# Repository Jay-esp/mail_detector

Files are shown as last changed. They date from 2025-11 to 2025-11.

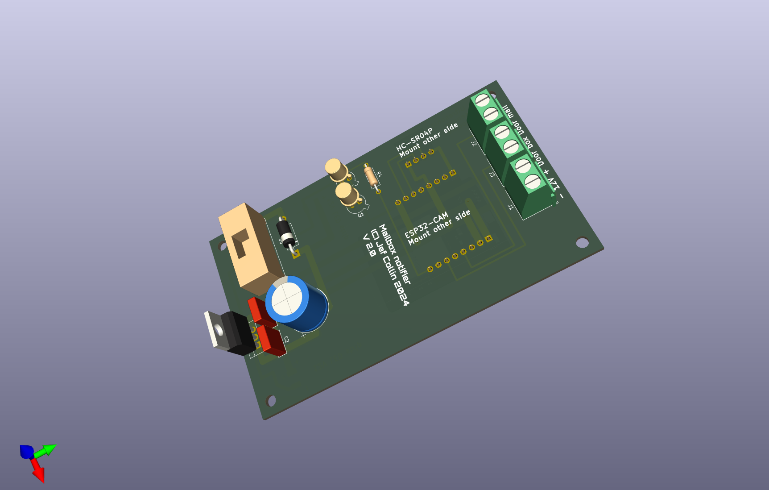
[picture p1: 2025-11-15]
design_pcb_schematic/mailbox_esp32_cam_v2_0_top.png

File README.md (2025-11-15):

Purpose is to send a mail and a picture when something is put in my physical mailbox.
This project is a new version of a mail detector i designed some time ago and that one served well for over 7 years.
The original version had an ESP8266, no camera, in 7 years i had to replace a reed contact due to poor quality and oxidation and update the software twice because the mail authenticiation for gmail changed.

My problem, i have a large brick mailbox in front of my house with a mail slot and in the back a separate door and storage for larger deliveries, i'm surprised how many notice the compartment and use it.

Mail, advertising, online order delivery... these days it can be at any time, sometimes they don't push it all the way in and when it rains i get soggy mail.

So i wanted a warning system that sends me a mail when something is put in either the mailbox or "box" box.

One of the challenges is that the mail slot is open, there is no flap or anything that moves when mail is put in.

The original concept was based on ESP8266 and a ultrasonic sensor HC-SR04P (3.3v version!), it is mounted above the slot and measures the distance to the floor of the mailbox, if the distance is short it means something is passing in the slot and it then activates wifi and sends a mail. Both doors have a reed sensor so i also get a notice when the box compartment is opened. I included a few leds to light the mailbox inside when i open the door, very handy at night, when i open the door that ignores any triggers that might happen when i pull stuck mail out of the flap. Of course a lot of extras such as stuck mail detection or door that is still open etc...

One of the challenges was power, i did have a socarex pipe nearby that only had the TV cable so i made an opening and ran a cable though it to my garage where a power supply is hooked up, to allow for a long cable i placed the 5v regulator in the mailbox so losses are no issue.

The version published here is a new design based on a ESP32-CAM and can take a picture of the mail, the same ultrasonic sensor is used, i changed the reed switches to a sealed version.

As usuall i use Arduino 1 IDE in portable mode to avoid the many issues with breaking changes in libraries.
I use the dedicated programming board they sell for the ESP32-CAM module since it has no USB-serial bridge on it.

Standard disclaimer: it works for me, i have no responsibility over what you make, use as inspiration or idea for your own project.

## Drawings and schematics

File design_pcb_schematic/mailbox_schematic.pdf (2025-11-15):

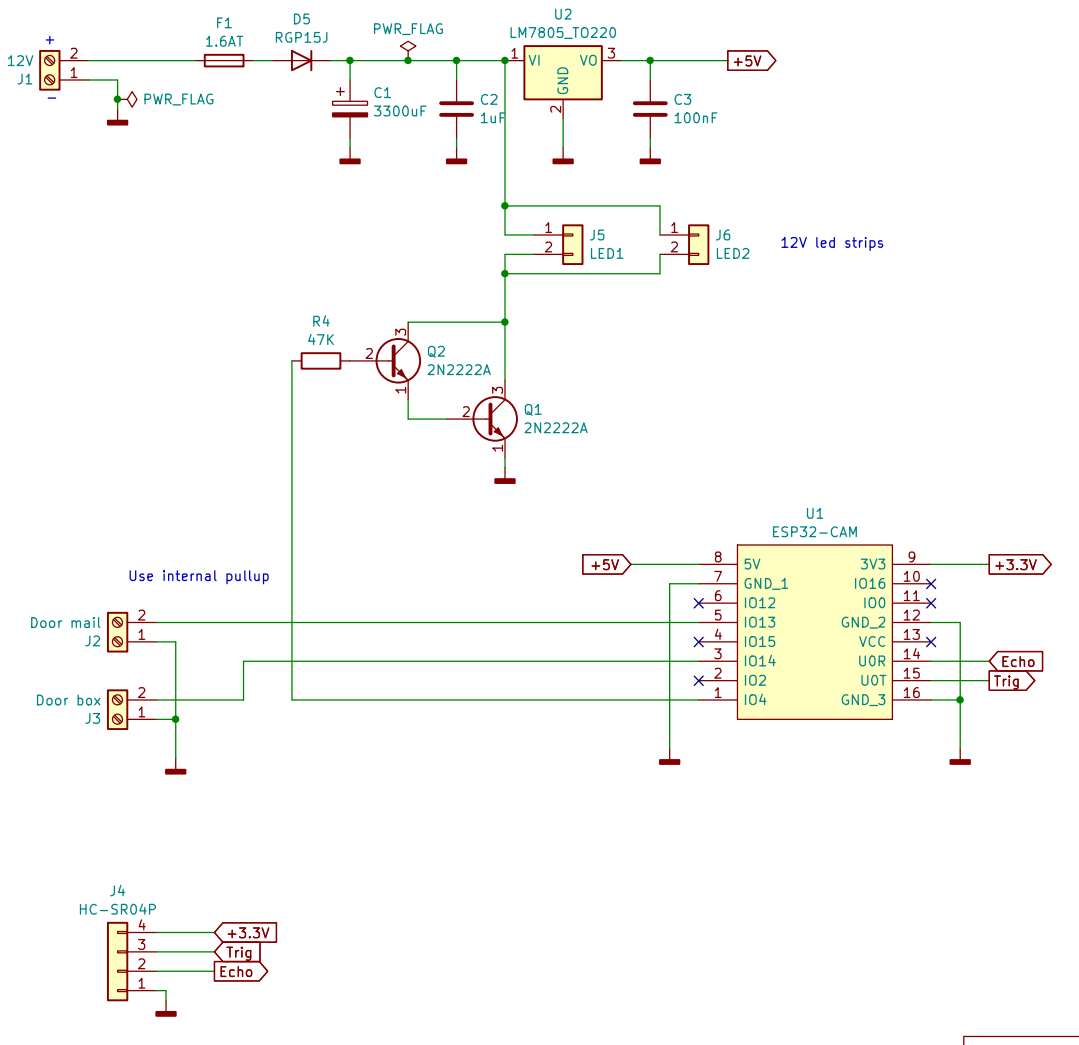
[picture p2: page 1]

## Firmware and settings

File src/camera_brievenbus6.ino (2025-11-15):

// mailbox detector
// Jef Collin 2024
// V 1.0


// todo


#include "esp_camera.h"
#include <WiFi.h>
#include "driver/rtc_io.h"
#include <ESP_Mail_Client.h>

boolean debugloop = false;

// wifi parameters
const char* ssid = "your_ssid";
const char* password = "your_password";

// SMTP parameters
#define AUTHOR_EMAIL    "xxx@gmail.com"
#define AUTHOR_PASSWORD "replace! make in gmail authenticiation"
#define SMTP_HOST        "smtp.gmail.com"
#define SMTP_PORT        465
#define RECIPIENT_EMAIL  "xxx@gmail.com"

#define EmailSubject     "My letterbox"

// cap on messages per day
#define MaximumMessagesPerDay 10

#define CAMERA_MODEL_AI_THINKER // Has PSRAM
#include <camera_pins.h>

// echo from sensor
#define Pin_Echo 3
// trigger for sensor
#define Pin_Trigger 1
// doorcontact mailbox
#define Pin_Door_Letter 13
// doorcontact packages
#define Pin_Door_Box 14
// LED strip
#define Pin_LEDS 4

// global buffer to duplicate picture buffer into so original buffer can be freed
uint8_t *PictureBuffer = NULL;
size_t PictureBufferLen = 0;

// distance measured
long EchoDistance = 0;

// trigger threshold in cm, modify as needed
int EchoTriggerDistance = 25;

// sensor triggered
boolean EchoTriggered = false;

// ignore echo sensor trigger if mailbox door is open
boolean EchoIgnoreTrigger = false;

// change status for echo and switches
boolean EchoStatus = false;
boolean PreviousEchoStatus = false;

byte LetterDoorStatus = 0;
byte PreviousLetterDoorStatus = 2;

byte BoxDoorStatus = 0;
byte PreviousBoxDoorStatus = 2;

// letter door open
boolean LetterDoorTriggered = false;

// if warning for open letter door is sent
boolean LetterDoorStillOpenWarningSent = false;

// box door open
boolean BoxDoorTriggered = false;

// if warning for open box door is sent
boolean BoxDoorStillOpenWarningSent = false;

// ignore box door if opened by me, open letter door first
boolean IgnoreBoxDoorTrigger = false;

// mail is stuck in opening
boolean MailStuck = false;

// LEDs status
boolean LEDIsOn = false;

// count number of emails, limit mails per day
int EmailCounter = 0;

// timer for sensors
unsigned long TimerEcho  = millis();
unsigned long TimerLetterDoor  = millis();
unsigned long TimerBoxDoor  = millis();

// timer for LEDs
unsigned long TimerLED  = millis();

// timer for mails per day
unsigned long TimerEmailLimit  = millis();

// minus 10 minutes to ensure mail is detected within time limit
unsigned long LastTrigger  = millis() - 600000;

// global used SMTPSession object for SMTP transport
SMTPSession smtp;

// global used Session_Config for user defined session credentials
Session_Config config;

/* callback function to get the Email sending status */
void smtpCallback(SMTP_Status status);

void setup() {
  if (debugloop) {
    Serial.begin(115200);
  }

  // configure inputs and outputs
  if (!debugloop) {
    pinMode(Pin_Trigger, OUTPUT);
    pinMode(Pin_Echo, INPUT);
    pinMode(Pin_Door_Letter, INPUT_PULLUP);
    pinMode(Pin_Door_Box, INPUT_PULLUP);
  }

  pinMode(Pin_LEDS, OUTPUT);
  digitalWrite(Pin_LEDS, LOW);

  // allow pins to settle
  delay(200);

  // make sure wifi is disabled
  WiFi.disconnect(true);

  WiFi.mode(WIFI_OFF);

  if (!debugloop) {
    // first measurement for power on mail
    EchoDistance = MeasureDistance();
  }

  //  network reconnection option
  MailClient.networkReconnect(true);

  // callback function to get the sending results
  smtp.callback(smtpCallback);

  if (debugloop) {
    //   smtp.debug(1);
  }

  // send startup mail
  SendMail(4, true);

  delay(5000);

}

void loop() {

  if (!debugloop) {

    // get door switches
    LetterDoorStatus = digitalRead(Pin_Door_Letter);
    BoxDoorStatus = digitalRead(Pin_Door_Box);

    // letter door flow
    if (LetterDoorStatus != PreviousLetterDoorStatus) {
      // letter door open
      if (LetterDoorStatus == 1) {
        // door opened
        // to avoid mails if we open the box door ignore triggers when letter door is open
        IgnoreBoxDoorTrigger = true;
        // ignore echo triggers if letter door open in case we need to pull out mail from the slot or push stuck mail in
        EchoIgnoreTrigger = true;
        // clear triggered
        EchoTriggered = false;
        // set trigger flag
        LetterDoorTriggered = true;
        // allow new mails
        EmailCounter = 0;
        // reset timer
        TimerEmailLimit = millis();
        // start timer
        TimerLetterDoor  = millis();
        // turn led on
        digitalWrite(Pin_LEDS, HIGH);
        LEDIsOn = true;
        // start timer
        TimerLED  = millis();
      }
      else
      {
        // reset, allow mails for box door
        IgnoreBoxDoorTrigger = false;
        // reset, arm echo sensor
        EchoIgnoreTrigger = false;
        // turn led off if still on
        if (LEDIsOn) {
          digitalWrite(Pin_LEDS, LOW);
          LEDIsOn = false;
        }
        LetterDoorTriggered = false;
        LetterDoorStillOpenWarningSent = false;
      }
      PreviousLetterDoorStatus = LetterDoorStatus;
    }

    // send warning once if still open after a while
    if (LetterDoorTriggered and millis() - TimerLetterDoor >= 300000 and !LetterDoorStillOpenWarningSent) {
      // door still open
      SendMail(3, false);
      // set flag to prevent from sending warning again
      LetterDoorStillOpenWarningSent = true;
    }

    // catch led on for a long time
    if (LEDIsOn and millis() - TimerLED >= 240000) {
      digitalWrite(Pin_LEDS, LOW);
      LEDIsOn = false;
    }

    // box door flow
    if (BoxDoorStatus != PreviousBoxDoorStatus) {
      // box door open
      if (BoxDoorStatus == 1) {
        // ignore box door if letter door is open
        if (!IgnoreBoxDoorTrigger) {
          // door opened
          SendMail(1, false);
          // set triggered
          BoxDoorTriggered = true;
          // start timer
          TimerBoxDoor = millis();
        }
      }
      else {
        // reset triggered
        BoxDoorTriggered = false;
        BoxDoorStillOpenWarningSent = false;
      }
      // keep current switch
      PreviousBoxDoorStatus = BoxDoorStatus;
    }

    // send warning once if still open after a while
    if (BoxDoorTriggered and millis() - TimerBoxDoor >= 1800000 and !BoxDoorStillOpenWarningSent) {
      // door still open
      SendMail(2, false);
      // set flag to prevent from sending warning again
      BoxDoorStillOpenWarningSent = true;
    }

    // echo flow
    if (!EchoIgnoreTrigger) {
      EchoDistance = MeasureDistance();
      EchoStatus = (EchoDistance <= EchoTriggerDistance);
      if (EchoStatus != PreviousEchoStatus) {
        // below trigger distance
        if (EchoStatus) {
          // already triggered
          if (EchoTriggered) {
            // check for stuck mail or 1 day timeout
            if ((millis() - TimerEcho >= 300000 and !MailStuck) or (millis() - TimerEcho >= 86400000 and MailStuck)) {
              SendMail(5, true);
              MailStuck = true;
              // reset timer
              TimerEcho = millis();
            }
          }
          else {
            // if not triggered yet send mail
            // ignore if less than 4 minutes after previous detection
            if (millis() - LastTrigger >= 240000) {
              SendMail(0, true);
              // set triggered
              EchoTriggered = true;
              // start timer
              TimerEcho = millis();
              // keep last trigger time
              LastTrigger = millis();
            }
          }
        }
        else {
          // clear triggered
          EchoTriggered = false;
          // reset post in klep
          MailStuck = false;
        }
        PreviousEchoStatus = EchoStatus;
      }
    }

  }
  else {
    // in test mode just take a picture and email every 5 seconds
    SendMail(0, true);

    delay(5000);
  }


  // time limit for emails per day
  if (millis() - TimerEmailLimit > 86400000) {
    // reset email counter allowing new emails
    EmailCounter = 0;
    // reset timer
    TimerEmailLimit = millis();
  }

  // loop delay
  delay(50);
}


// measure distance
long MeasureDistance(void) {
  long duration;
  float distance;
  // set default to max distance in case of timeout
  long returndistance = 200;

  // sensor is triggered by a HIGH pulse of 10 or more microseconds.
  // short LOW pulse beforehand to ensure a clean HIGH pulse
  digitalWrite(Pin_Trigger, LOW);
  delayMicroseconds(5);
  digitalWrite(Pin_Trigger, HIGH);
  delayMicroseconds(10);
  digitalWrite(Pin_Trigger, LOW);

  // read the signal from the sensor: a HIGH pulse whose
  // duration is the time (in microseconds) from the sending
  // of the ping to the reception of its echo off of an object.
  // wait for max 12000 us = ca 200 cm
  duration = pulseIn(Pin_Echo, HIGH, 12000);

  if (duration > 0) {
    // convert the time into a distance in cm
    distance = (duration / 2) * 0.0343;
    // round
    returndistance = long(distance + 0.5);
    if (returndistance > 200) {
      returndistance = 200;
    }
  }
  return returndistance;
}


// send the mail, take picture is required
void SendMail(byte messagemode, boolean takepicture) {

  // check if limit is exceeded
  if (EmailCounter < MaximumMessagesPerDay) {

    String mailmessage;
    switch (messagemode) {
      case 0:
        // mail detected
        mailmessage = F("Post in de brievenbus.");
        break;

      case 1:
        // box door is opened
        mailmessage = F("Pakjesdeur geopend.");
        break;

      case 2:
        // box door is still open
        mailmessage = F("Pakjesdeur te lang open.");
        break;

      case 3:
        // letter door is still open
        mailmessage = F("Deur van brieven staat nog open.");
        break;

      case 4:
        // startup message
        mailmessage = F("Detector opgestart.");
        break;

      case 5:
        // mail stuck
        mailmessage = F("Post vast in de klep.");
        break;

    }

    // warning if nr of messages is reached
    if (EmailCounter == MaximumMessagesPerDay - 1) {
      mailmessage = mailmessage + "\nLimiet bereikt, geen verdere berichten voor vandaag!";
    }

    if (takepicture) {
      initializeCamera();
      // led on
      digitalWrite(Pin_LEDS, HIGH);
      delay(300);

      // capture the jpg image from camera
      camera_fb_t * fb = NULL;
      // take a number of pictures to allow camera to adjust
      for (byte x = 0; x < 15; x++) {
        fb = esp_camera_fb_get();
        esp_camera_fb_return(fb); // dispose the buffered image
        fb = NULL; // reset to capture errors
      }
      fb = esp_camera_fb_get(); // get fresh image

      // led off
      digitalWrite(Pin_LEDS, LOW);

      // allocate memory for the buffer
      PictureBufferLen = fb->len;
      PictureBuffer = (uint8_t *)malloc(PictureBufferLen);
      // copy the picture to the buffer
      memcpy(PictureBuffer, fb->buf, PictureBufferLen);

      // release the camera to reduce power before turning on wifi
      esp_camera_fb_return(fb);

      esp_camera_deinit();

      // power down the camera
      powerDownCamera();

    }

    // setup wifi
    WiFi.begin(ssid, password);

    WiFi.setSleep(false);

    int WiFiConnectRetries = 0;
    // limit retries to avoid hangups
    while (WiFi.status() != WL_CONNECTED) {
      delay(500);
      WiFiConnectRetries++;
      if (WiFiConnectRetries > 360) {
        exit;
      }
    }
    if (WiFiConnectRetries > 360) {
      // limit reached, connection failed

    }
    else {
      // Serial.println(WiFi.localIP());

      config.server.host_name = SMTP_HOST;
      config.server.port = SMTP_PORT;
      config.login.email = AUTHOR_EMAIL;
      config.login.password = AUTHOR_PASSWORD;

      // For client identity, assign invalid string can cause server rejection
      config.login.user_domain = "gmail.com";

      //  /*
      //    Set the NTP config time
      //    For times east of the Prime Meridian use 0-12
      //    For times west of the Prime Meridian add 12 to the offset.
      //    Ex. American/Denver GMT would be -6. 6 + 12 = 18
      //    See https://en.wikipedia.org/wiki/Time_zone for a list of the GMT/UTC timezone offsets
      //  */
      config.time.ntp_server = "pool.ntp.org,time.nist.gov";
      config.time.gmt_offset = 1;
      config.time.day_light_offset = 0;

      // Declare the SMTP_Message class variable to handle to message being transport
      SMTP_Message message;

      /* Enable the chunked data transfer with pipelining for large message if server supported */
      message.enable.chunking = true;

      // message headers
      message.sender.name = AUTHOR_EMAIL;
      message.sender.email = AUTHOR_EMAIL;
      message.subject = EmailSubject;
      message.addRecipient("Jef", RECIPIENT_EMAIL);
      // message content

      // startup message, add wifi parameter
      if (messagemode == 4) {
        mailmessage = mailmessage + "\nWiFi signaal " + String(WiFi.RSSI()) + " dBm.";
      }

      message.text.content = mailmessage;

      message.html.transfer_encoding = Content_Transfer_Encoding::enc_7bit;

      message.html.charSet = F("utf-8");

      // attach if picture taken
      if (takepicture) {

        // Declare the attachment data
        SMTP_Attachment att;

        att.descr.filename = "mailbox.jpg";
        att.descr.mime = "image/jpg";

        att.blob.data = PictureBuffer;
        att.blob.size = PictureBufferLen;

        att.descr.content_id = F("image-001"); // The content id (cid) of camera.jpg image in the src tag

        att.descr.transfer_encoding = Content_Transfer_Encoding::enc_base64;

        message.addAttachment(att);

      }

      //   Serial.println("Connection setup");

      boolean ConnectionOk = false;
      for (byte ConnectionRetry = 0; ConnectionRetry < 5; ConnectionRetry++ ) {
        /* connect to the server */
        if (smtp.connect(&config))
        {
          //    Serial.println("Connection ok");
          ConnectionOk = true;
          break;
        }
        else {
          //      Serial.println("Connection error-retry");
        }
      }

      if (ConnectionOk and smtp.isAuthenticated()) {
        // send the Email and close the session
        if (!MailClient.sendMail(&smtp, &message, true)) {
          //       Serial.println("Error authen");
        }
      }
    }

    // shutdown wifi
    WiFi.disconnect(true, true);

    WiFi.mode(WIFI_OFF);

    // count mails sent
    EmailCounter++;
  }
}

// setup camera
bool initializeCamera(void) {
  // ensure the camera is properly powered up
  powerUpCamera();
  delay(100); // ensure proper power up time

  camera_config_t config;
  config.ledc_channel = LEDC_CHANNEL_0;
  config.ledc_timer = LEDC_TIMER_0;
  config.pin_d0 = Y2_GPIO_NUM;
  config.pin_d1 = Y3_GPIO_NUM;
  config.pin_d2 = Y4_GPIO_NUM;
  config.pin_d3 = Y5_GPIO_NUM;
  config.pin_d4 = Y6_GPIO_NUM;
  config.pin_d5 = Y7_GPIO_NUM;
  config.pin_d6 = Y8_GPIO_NUM;
  config.pin_d7 = Y9_GPIO_NUM;
  config.pin_xclk = XCLK_GPIO_NUM;
  config.pin_pclk = PCLK_GPIO_NUM;
  config.pin_vsync = VSYNC_GPIO_NUM;
  config.pin_href = HREF_GPIO_NUM;
  config.pin_sccb_sda = SIOD_GPIO_NUM;
  config.pin_sccb_scl = SIOC_GPIO_NUM;
  config.pin_pwdn = PWDN_GPIO_NUM;
  config.pin_reset = RESET_GPIO_NUM;
  config.xclk_freq_hz = 20000000;
  config.pixel_format = PIXFORMAT_JPEG;
  // large size if psram is present, it is on esp32-cam
  config.frame_size = FRAMESIZE_UXGA;
  // Image sizes: 160x120 (QQVGA), 128x160 (QQVGA2), 176x144 (QCIF), 240x176 (HQVGA), 320x240 (QVGA),
  //              400x296 (CIF), 640x480 (VGA, default), 800x600 (SVGA), 1024x768 (XGA), 1280x1024 (SXGA),
  //              1600x1200 (UXGA)
  config.jpeg_quality = 10;                     // 0-63 lower number means higher quality (can cause failed image capture if set too low at higher resolutions)
  config.grab_mode = CAMERA_GRAB_WHEN_EMPTY;
  config.fb_count = 1;

  //  // Init with high specs to pre-allocate larger buffers
  //  if (psramFound()) {
  //    config.frame_size = FRAMESIZE_UXGA;
  //    config.jpeg_quality = 10;
  //    config.fb_count = 2;
  //  } else {
  //    config.frame_size = FRAMESIZE_SVGA;
  //    config.jpeg_quality = 12;
  //    config.fb_count = 1;
  //  }

  // deinitialize the camera before initializing it again
  esp_camera_deinit();

  // Camera init
  if (esp_camera_init(&config) != ESP_OK) {
    //   Serial.println("Camera init failed");
    return false;
  }

  cameraImageSettings();

  return true;
}

void powerDownCamera() {
  pinMode(PWDN_GPIO_NUM, OUTPUT);
  digitalWrite(PWDN_GPIO_NUM, HIGH);
}

void powerUpCamera() {
  pinMode(PWDN_GPIO_NUM, OUTPUT);
  digitalWrite(PWDN_GPIO_NUM, LOW);
  delay(100); // Wait for camera to power up
}

// callback function to get the Email sending status
void smtpCallback(SMTP_Status status)
{
  //  /* Print the current status */
  //  Serial.println(status.info());

  /* Print the sending result */
  if (status.success())
  {
    // MailClient.printf used in the examples is for format printing via debug Serial port
    // that works for all supported Arduino platform SDKs e.g. SAMD, ESP32 and ESP8266.
    // In ESP8266 and ESP32, you can use Serial.printf directly.

    //    Serial.println("----------------");
    //    MailClient.printf("Message sent success: %d\n", status.completedCount());
    //    MailClient.printf("Message sent failed: %d\n", status.failedCount());
    //    Serial.println("----------------\n");

    //    for (size_t i = 0; i < smtp.sendingResult.size(); i++)
    //    {
    //      /* Get the result item */
    //      SMTP_Result result = smtp.sendingResult.getItem(i);
    //
    //      // In case, ESP32, ESP8266 and SAMD device, the Timer get from result.Timer should be valid if
    //      // your device time was synched with NTP server.
    //      // Other devices may show invalid Timer as the device time was not set i.e. it will show Jan 1, 1970.
    //      // You can call smtp.setSystemTime(xxx) to set device time manually. Where xxx is Timer (seconds since Jan 1, 1970)
    //
    //      MailClient.printf("Message No: %d\n", i + 1);
    //      MailClient.printf("Status: %s\n", result.completed ? "success" : "failed");
    //      MailClient.printf("Date/Time: %s\n", MailClient.Time.getDateTimeString(result.Timer, "%B %d, %Y %H:%M:%S").c_str());
    //      MailClient.printf("Recipient: %s\n", result.recipients.c_str());
    //      MailClient.printf("Subject: %s\n", result.subject.c_str());
    //    }
    //    Serial.println("----------------\n");

    // You need to clear sending result as the memory usage will grow up.
    smtp.sendingResult.clear();
  }
}


// set camera specific parameters
bool cameraImageSettings() {

  //    s->set_brightness(s, 1);               // I want image about 1 stop brighter (-2 to 2)
  //    s->set_contrast(s, 0);
  //    s->set_saturation(s, 0);
  //    s->set_gain_ctrl(s, 0);                // Auto gain off
  //    s->set_exposure_ctrl(s, 0);            // Auto exposure off
  //    s->set_aec_value(s, 100);              // Set aec to a small initial value.
  //    s->set_awb_gain(s, 1);                 // Auto White Balance enable (0 or 1)
  //    s->set_wb_mode(s, 0);                  // If awb_gain enabled (0-Auto,1-Sunny,2-Cloudy,3-Office,4-Home)
  //    s->set_aec2(s, 1);                     // AEC DSP
  //    s->set_bpc(s, 1);                      // Black point control
  //    s->set_wpc(s, 1);                      // White point control
  //    s->set_lenc(s, 1);                     // Lens correction
  //


  sensor_t *s = esp_camera_sensor_get();

  // enable auto adjust
  s->set_gain_ctrl(s, 1);                       // auto gain on
  s->set_exposure_ctrl(s, 1);                   // auto exposure on
  s->set_awb_gain(s, 1);                        // Auto White Balance enable (0 or 1)
  s->set_brightness(s, 0);  // (-2 to 2) - set brightness

  //  // Apply manual settings
  //  //  s->set_gain_ctrl(s, 0);                       // auto gain off
  //  //  s->set_awb_gain(s, 1);                        // Auto White Balance enable (0 or 1)
  //  //  s->set_exposure_ctrl(s, 0);                   // auto exposure off
  //  //  s->set_brightness(s, 0);  // (-2 to 2) - set brightness
  //  //  s->set_agc_gain(s, 0);          // set gain manually (0 - 30)
  //  //  s->set_aec_value(s, 0);     // set exposure manually  (0-1200)

  //  //s->set_vflip(s, 1);                               // flip image vertically
  //  //s->set_hmirror(s, 1);                             // flip image horizontally

  return 1;
}
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

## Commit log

2025-11-15 Update README with programming board details
    Added information about the programming board used for ESP32-CAM.
2025-11-15 Fix typo in ultrasonic sensor model in README
